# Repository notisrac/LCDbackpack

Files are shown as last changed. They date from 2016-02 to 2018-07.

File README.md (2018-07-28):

# LCD Backpack (serial/I2C)

[Arduino](https://www.arduino.cc/) based character LCD driver circuit, with a form factor that lets it be mounted to the back of a display.
It can be used with any [Hitachi HD44780](https://en.wikipedia.org/wiki/Hitachi_HD44780_LCD_controller) based LCD, or compatible VFD displays (ex.: [Noritake-Itron VFDs](http://www.noritake-itron.com/NewWeb/GVFD/Overview/Overview.asp)).
Supports displays with a single row (1x16) or double row (2x8) connectors.
The display is controlled through a [74HC595](http://www.nxp.com/documents/data_sheet/74HC_HCT595.pdf) shift register.

## Features
* Supports any Hitachi HD44780 based character LCD (or VFD)
* 1x16 and 2x8 pins
* Arduino compatible device with most of the GPIO pins accessible
* Serial and [I2C](https://en.wikipedia.org/wiki/I%C2%B2C) ports
* [FTDI](https://www.adafruit.com/product/284) and (6 pin) [ICSP](https://en.wikipedia.org/wiki/In-system_programming) programming ports
* On-board voltage regulator
* Contrast pot
* Backlight controllable from code (QC pin on the shift register)
* It is the same size as a 16x2 character LCD (also the mounting holes line up)

## Ports
* Serial (D0, D1)
* I2C (A4, A5)
* FTDI header
* ICSP

## Usable Arduino GPIO pins
* Analog: A0, A1, A2, A3, A4, A5
* Digital: D2, D3, D4, D5, D6, D7, D8, D9, D12

## Power supply
The board has an on board power connector, that powers the backpack and the display too.
You can use a voltage regulator like the [LD1117](http://www.st.com/web/en/resource/technical/document/datasheet/CD00000544.pdf), or if you have a regulated power supply, you can just leave it unpopulated and short pins 2 and 3 together.

## Shift register pinout
* QA  - Not connected 
* QB  - LCD RS
* QC  - LCD Backlight control
* QD  - LCD E
* QE  - LCD DB4
* QF  - LCD DB5
* QG  - LCD DB6
* QH  - LCD DB7
* QH* - Not connected
* SER - Arduino D11
* SCK - Arduino D13
* RCK - Arduino D10

## Errata
* Due to the fact, that the enable line of the display is tied to one of the shift register pins, this construction does not work with any of the standard libraries. You need to use the provided library to drive the display!
* In the first version of the board layout the isolation of the ground fill was set to 0. This could have caused a short.

## Pictures
Assembled:
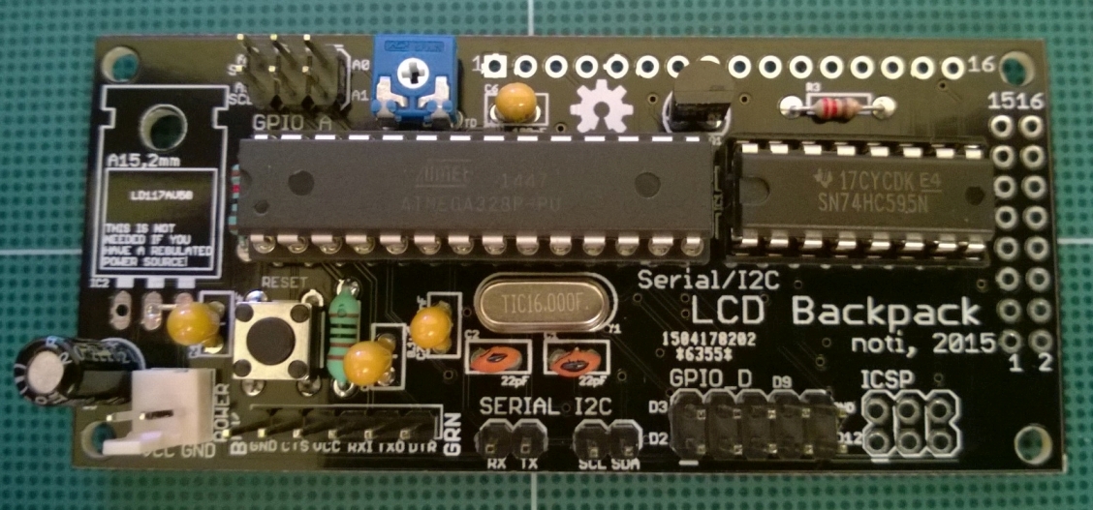
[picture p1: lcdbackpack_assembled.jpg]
LCD backpack assembled


Schematic:
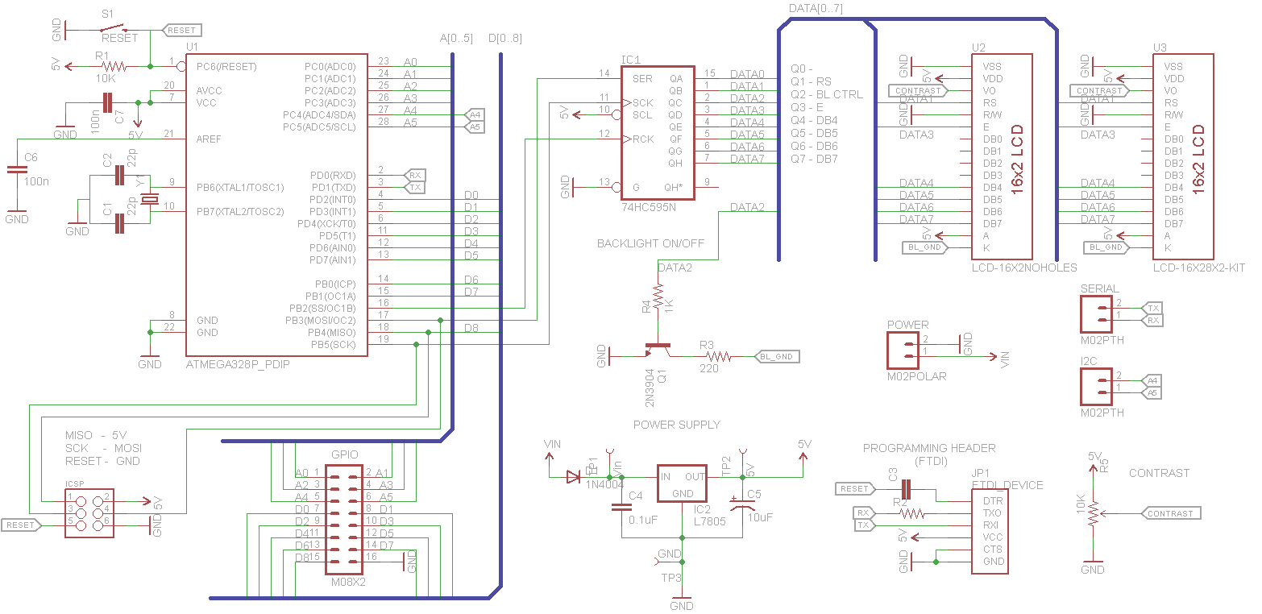
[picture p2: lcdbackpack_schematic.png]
LCD backpack schematic


*Made with Cadsoft Eagle v6.5.0*

Analytics (https://github.com/igrigorik/ga-beacon)

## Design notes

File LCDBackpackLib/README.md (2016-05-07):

# LCDBackpackLib
Since the LCDBackpack uses a different schematic, than the other LCD libraries, you need to use this library to be able to make the LCDBackpack work.

##Acknowledgements
raron's ShiftRegLCD123 - this lib is based on raron's work:
  http://code.google.com/p/shiftreglcd123/

A proper initialization routine for HD44780 compatible LCD's:
  http://web.alfredstate.edu/weimandn/lcd/lcd_initialization/lcd_initialization_index.html

##Schematic
See the project page: https://github.com/notisrac/LCDbackpack

##Connections

  Requires 3 pins from the Arduino.

SR output - Wiring:
*  Bit  #0   - N/C - not connected.
*  Bit  #1   - connects to RS (Register Select) on the LCD
*  Bit  #2   - N/C or LCD backlight. Do not connect directly! Use a driver / transistor!
*  Bit  #3   - connects to LCD Enable input.
*  Bits #4-7 - connects to LCD data inputs D4 - D7.
*  LCD R/!W-pin hardwired to LOW (only writing to LCD).

##Usage

```c
#include <LCDBackpackLib.h>

const byte dataPin = 11;    // SR Data from Arduino pin 10
const byte clockPin = 13;    // SR Clock from Arduino pin 11
const byte latchPin = 10;   // LCD enable from Arduino pin 12

// Instantiate an LCD object
LCDBackpackLib lcdbp(dataPin, clockPin, latchPin);

void setup()
{
	// initialize LCD and set display size
	// LCD size 20 columns x 2 lines, small (normal) font
	lcdbp.begin(20, 2);

	// Turn on backlight (if used)
	lcdbp.backlightOn();

	// Print a message to the LCD.
	lcdbp.print("HELLO, WORLD!");

	// move to next line
	lcdbp.setCursor(0, 1);
	lcdbp.print("LCDBackpackLib test"); 
}

void loop()
{
}
```

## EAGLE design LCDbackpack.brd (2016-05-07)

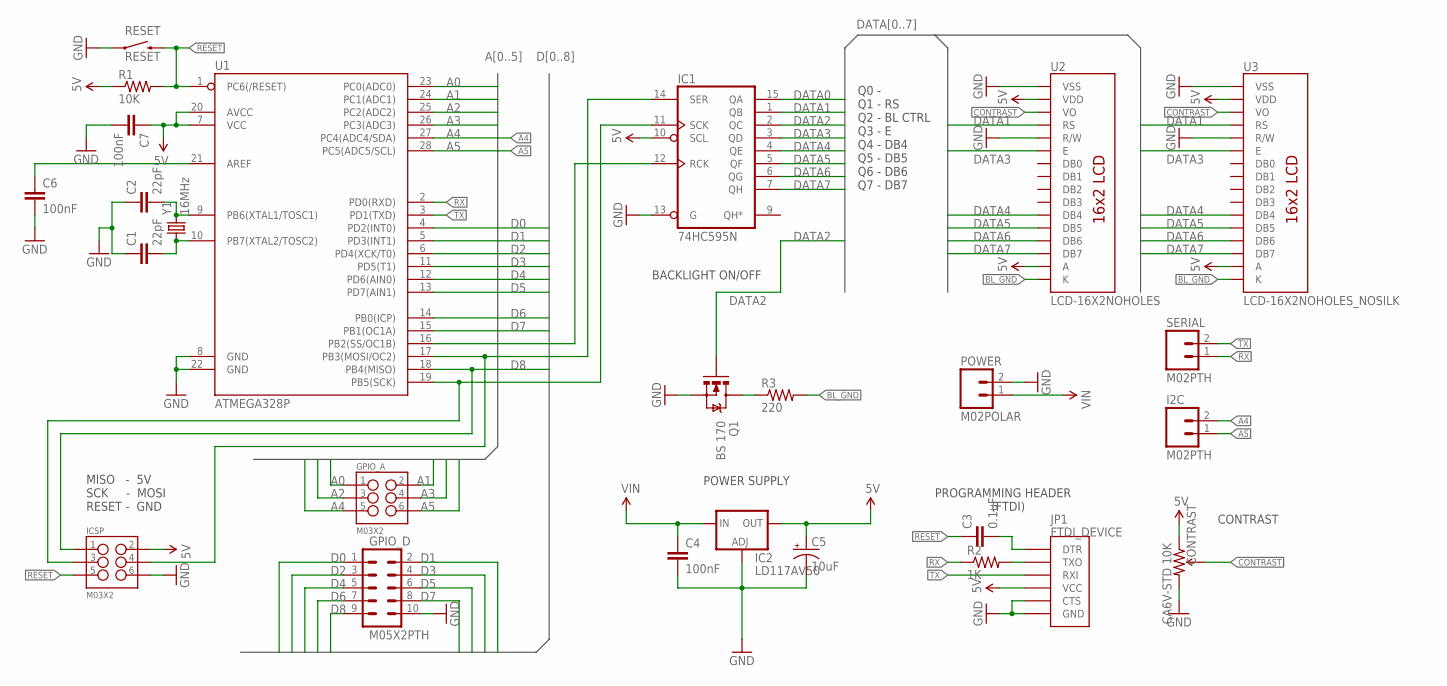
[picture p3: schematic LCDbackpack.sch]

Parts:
C1, C2: 22pF; CAP-PTH-SMALL2
C3: 0.1uF; CAP-PTH-SMALL2
C4, C6, C7: 100nF; CAP-PTH-SMALL2
C5: 10uF; CPOL-RADIAL-10UF-25V
CONTRAST: CA6V-STD 10K; TRIM_POT_PTH
GPIO_A: M03X2; 2X3
GPIO_D: M05X2PTH; AVR_ICSP
I2C: M02PTH; 1X02
IC1: 74HC595N; DIL16
IC2: LD117AV50; TO220L1
ICSP: M03X2; 2X3_POGO
JP1: FTDI_DEVICE; FTDI_DEVICE_SIDE
POWER: M02POLAR; MOLEX-1X2
Q1: BS 170; TO-92
R1: 10K; AXIAL-0.3
R2: 1K; AXIAL-0.3
R3: 220; AXIAL-0.3
RESET: RESET; TACTILE-PTH
SERIAL: M02PTH; 1X02
U1: ATMEGA328P; DIL28-3
U2: LCD-16X2NOHOLES; LCD-16X2_NOHOLES
U3: LCD-16X2NOHOLES_NOSILK; LCD-8X2_NOHOLES_NOSILK
Y1: 16MHz; HC49US

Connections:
A0: GPIO_A.1, U1.23 (PC0(ADC0))
A1: GPIO_A.2, U1.24 (PC1(ADC1))
A2: GPIO_A.3, U1.25 (PC2(ADC2))
A3: GPIO_A.4, U1.26 (PC3(ADC3))
A4: GPIO_A.5, I2C.2, U1.27 (PC4(ADC4/SDA))
A5: GPIO_A.6, I2C.1, U1.28 (PC5(ADC5/SCL))
BL_GND: R3.P$2 (2), U2.16 (K), U3.16 (K)
CONTRAST: CONTRAST.2 (WIPER), U2.3 (VO), U3.3 (VO)
D0: GPIO_D.1, U1.4 (PD2(INT0))
D1: GPIO_D.2, U1.5 (PD3(INT1))
D2: GPIO_D.3, U1.6 (PD4(XCK/T0))
D3: GPIO_D.4, U1.11 (PD5(T1))
D4: GPIO_D.5, U1.12 (PD6(AIN0))
D5: GPIO_D.6, U1.13 (PD7(AIN1))
D6: GPIO_D.7, U1.14 (PB0(ICP))
D7: GPIO_D.8, U1.15 (PB1(OC1A))
D8: GPIO_D.9, ICSP.P$1 (1), U1.18 (PB4(MISO))
DATA0: IC1.15 (QA)
DATA1: IC1.1 (QB), U2.4 (RS), U3.4 (RS)
DATA2: IC1.2 (QC), Q1.2 (G)
DATA3: IC1.3 (QD), U2.6 (E), U3.6 (E)
DATA4: IC1.4 (QE), U2.11 (DB4), U3.11 (DB4)
DATA5: IC1.5 (QF), U2.12 (DB5), U3.12 (DB5)
DATA6: IC1.6 (QG), U2.13 (DB6), U3.13 (DB6)
DATA7: IC1.7 (QH), U2.14 (DB7), U3.14 (DB7)
GND: C1.1, C2.1, C4.2, C5.2 (-), C6.2, C7.2, CONTRAST.3 (CW), GPIO_D.10, IC1.8 (GND), IC1.13 (G), IC2.1 (ADJ), ICSP.P$6 (6), JP1.P$5 (CTS), JP1.P$6 (GND), POWER.2, Q1.1 (S), RESET.1, U1.8 (GND), U1.22 (GND), U2.1 (VSS), U2.5 (R/W), U3.1 (VSS), U3.5 (R/W)
unnamed: C3.2, JP1.P$1 (DTR)
unnamed: JP1.P$2 (TXO), R2.P$2 (2)
unnamed: C2.2, U1.9 (PB6(XTAL1/TOSC1)), Y1.2
unnamed: C1.2, U1.10 (PB7(XTAL2/TOSC2)), Y1.1
unnamed: IC1.14 (SER), ICSP.P$4 (4), U1.17 (PB3(MOSI/OC2))
unnamed: Q1.3 (D), R3.P$1 (1)
unnamed: IC1.12 (RCK), U1.16 (PB2(SS/OC1B))
unnamed: IC1.11 (SCK), ICSP.P$3 (3), U1.19 (PB5(SCK))
unnamed: C6.1, U1.21 (AREF)
RESET: C3.1, ICSP.P$5 (5), R1.P$2 (2), RESET.3 (2), U1.1 (PC6(/RESET))
RX: R2.P$1 (1), SERIAL.1, U1.2 (PD0(RXD))
TX: JP1.P$3 (RXI), SERIAL.2, U1.3 (PD1(TXD))
VCC: C5.1 (+), C7.1, CONTRAST.1 (CCW), IC1.10 (SCL), IC1.16 (VCC), IC2.2 (OUT), ICSP.P$2 (2), JP1.P$4 (VCC), R1.P$1 (1), U1.7 (VCC), U1.20 (AVCC), U2.2 (VDD), U2.15 (A), U3.2 (VDD), U3.15 (A)
VIN: C4.1, IC2.3 (IN), POWER.1

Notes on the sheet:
POWER SUPPLY
PROGRAMMING HEADER (FTDI)
CONTRAST
BACKLIGHT ON/OFF
Q0 - Q1 - RS Q2 - BL CTRL Q3 - E Q4 - DB4 Q5 - DB5 Q6 - DB6 Q7 - DB7
MISO - 5V SCK - MOSI RESET - GND

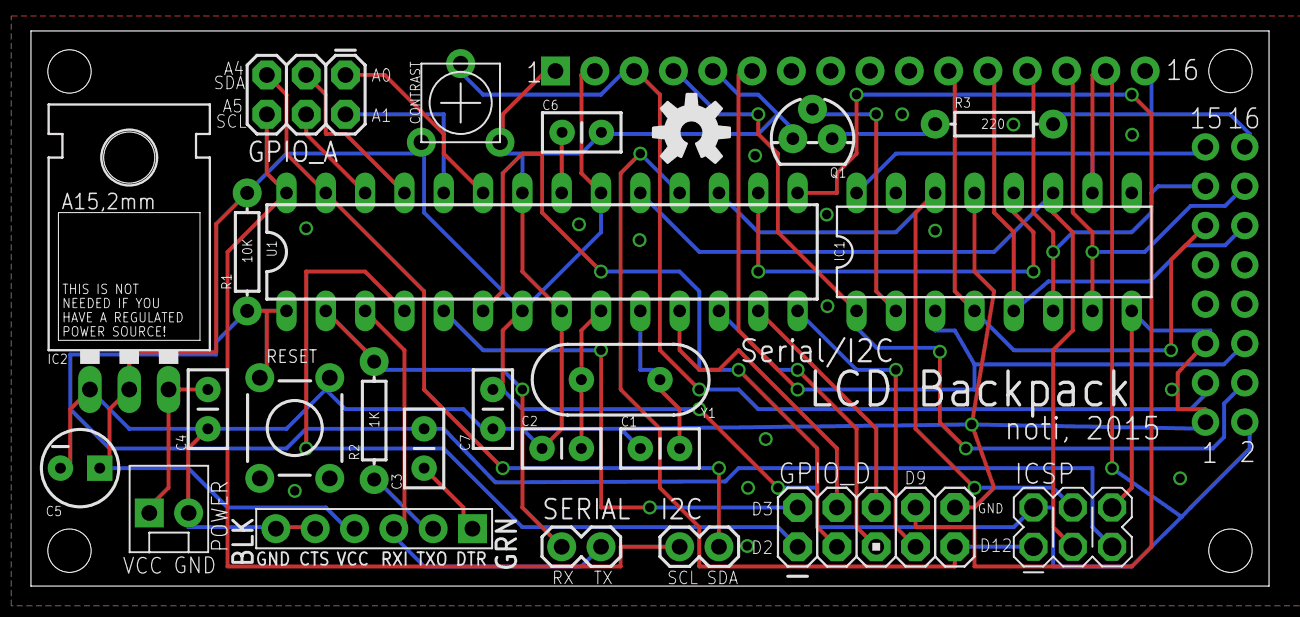
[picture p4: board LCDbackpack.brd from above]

Board: 2 copper layers, 80.0 x 35.9 mm, 27 parts (1 on the bottom side), 39 nets.

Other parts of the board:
U$1: OSHW-LOGO-M

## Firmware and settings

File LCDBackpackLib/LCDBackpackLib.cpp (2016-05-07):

/*

LCDBackpackLib - Arduino library for driving the LCD display on the LCDBackpack


Copyright (C) 2016 noti

GNU GPLv3 license

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

Contact: notix@freemail.hu


Acknowledgements:

  raron's ShiftRegLCD123 - this lib is based on raron's work:
    http://code.google.com/p/shiftreglcd123/
  A proper initialization routine for HD44780 compatible LCD's:
    http://web.alfredstate.edu/weimandn/lcd/lcd_initialization/lcd_initialization_index.html


For reference / schematics:

Project homepage: https://github.com/notisrac/LCDbackpack


CONNECTION DESCRIPTIONS

  Requires 3 pins from the Arduino.

SR output:  Wiring:
  Bit  #0   - N/C - not connected.
  Bit  #1   - connects to RS (Register Select) on the LCD
  Bit  #2   - N/C or LCD backlight. Do not connect directly!
              Use a driver / transistor!
  Bit  #3   - connects to LCD Enable input.
  Bits #4-7 - connects to LCD data inputs D4 - D7.

  LCD R/!W-pin hardwired to LOW (only writing to LCD).


USAGE:

  1: Make an LCD object, set arduino output pins and LCD wiring scheme:

        ShiftRegLCD123 LCDobject( Datapin , Clockpin, Latchpin )

    where:
      Datapin : Arduino pin to shiftregister serial data input. D11
      Clockpin: Arduino pin to shiftregister clock input. D13
      Latchpin: Arduino pin to shiftregister latch/strobe/register clock input. D10

  2: Initialize the LCD by calling begin() function with LCD size and font:

        LCDobject.begin( cols, lines [, font] )

    where:
      cols    : Nr. of columns in the LCD
      lines   : Nr. of "logical lines" in the LCD (not neccesarily physical)
      font    : 0 = small (default), 1 = large font for some 1-line LCD's only.


History
2016.04.17 noti - first version

*/

#include "LCDBackpackLib.h"
#include <stdio.h>
#include <inttypes.h>

#if defined(ARDUINO) && ARDUINO >= 100
#include "Arduino.h"
#else
#include "WProgram.h"
#endif


LCDBackpackLib::LCDBackpackLib(uint8_t srdata, uint8_t srclock, uint8_t srlatch)
{
	init(srdata, srclock, srlatch);
}


void LCDBackpackLib::init(uint8_t srdata, uint8_t srclock, uint8_t srlatch)
{
	_srdata_pin = srdata;
	_srclock_pin = srclock;
	_srlatch_pin = srlatch;
	_backlight = 0;       // Defaults to backlight off.

	pinMode(_srclock_pin, OUTPUT);
	pinMode(_srdata_pin, OUTPUT);
	pinMode(_srlatch_pin, OUTPUT);

	//digitalWrite(_srlatch_pin, LOW);
	shiftOut(_srdata_pin, _srclock_pin, MSBFIRST, 0x00);
	digitalWrite(_srlatch_pin, LOW);
}

void LCDBackpackLib::begin(uint8_t cols, uint8_t lines)
{
	begin(cols, lines, 0);
}

void LCDBackpackLib::begin(uint8_t cols, uint8_t lines, uint8_t font)
{
	_numlines = lines;
	_cols = cols;    // Only used for identifying 16x4 LCD, nothing else.

	if (lines > 1)
	{
		_displayfunction = LCD_4BITMODE | LCD_2LINE;
	}
	else
	{
		_displayfunction = LCD_4BITMODE | LCD_1LINE;
	}


	// For some 1-line displays you can select a 10 pixel high font
	if (font != 0 && lines == 1)
	{
		_displayfunction |= LCD_5x10DOTS;
	}
	else
	{
		_displayfunction |= LCD_5x8DOTS;
	}

	// SEE PAGE 45/46 FOR INITIALIZATION SPECIFICATION!
	// according to datasheet, we need at least 40ms after power rises above 2.7V
	// before sending commands. Arduino can turn on way before 4.5V so we'll wait 
	// more.
	// Also check this -excellent- guide on HD44780-based LCD initializations:
	// http://web.alfredstate.edu/weimandn/lcd/lcd_initialization/lcd_initialization_index.html
	// (From which this initialization and comments are taken from)
	// ---------------------------------------------------------------------------

	// Step 1.   Power on, then delay > 100 ms
	//delay(200);
	for (int i = 0; i < 200; ++i)
	{
		delayMicroseconds(1000);  // Waits 200 ms just in case.
	}

	// Step 2.   Instruction 0011b (3h), then delay > 4.1 ms 
	send(LCD_FUNCTIONSET | LCD_8BITMODE, MODE_INIT);
	delayMicroseconds(4500);  // wait more than 4.1ms

	// Step 3.   Instruction 0011b (3h), then delay > 100 us
	//   NOTE: send()/command() and init4bits() functions adds 60 us delay
	send(LCD_FUNCTIONSET | LCD_8BITMODE, MODE_INIT);
	delayMicroseconds(40);

	// Step 4.   Instruction 0011b (3h), then delay > 100 us 
	send(LCD_FUNCTIONSET | LCD_8BITMODE, MODE_INIT);
	delayMicroseconds(40);

	// Step 5.   Instruction 0010b (2h), then delay > 100 us (speculation)
	//   This is where display is set to 4-bit interface
	send(LCD_FUNCTIONSET | LCD_4BITMODE, MODE_INIT);
	delayMicroseconds(40);

	// Step 6.   Instruction 0010b (2h), then 1000b (8h), then delay > 53 us or check BF 
	//   Set nr. of logical lines (not neccesarily physical lines) and font size
	//   (usually 2 lines and small font)
	command(LCD_FUNCTIONSET | _displayfunction);
	//delayMicroseconds(60);

	// Step 7.   Instruction 0000b (0h), then 1000b (8h) then delay > 53 us or check BF
	command(LCD_DISPLAYCONTROL);
	//delayMicroseconds(60);

	// Step 8.   Instruction 0000b (0h), then 0001b (1h) then delay > 3 ms or check BF 
	//   This is a Clear display instruction and takes a lot of time
	command(LCD_CLEARDISPLAY);
	delayMicroseconds(3000);

	// Step 9.   Instruction 0000b (0h), then 0110b (6h), then delay > 53 us or check BF 
	//   Initialize to default text direction (for romance languages)
	_displaymode = LCD_ENTRYLEFT | LCD_ENTRYSHIFTDECREMENT;
	command(/*LCD_DISPLAYCONTROL*/ LCD_ENTRYMODESET | _displaymode);
	//delayMicroseconds(60);

	// Step 10. Not really a step, but initialization has ended. Except display is turned off.

	// Step 11.   Instruction 0000b (0h), then 1100b (0Ch), then delay > 53 us or check BF
	//   Turn display on, no cursor, no cursor blinking.
	_displaycontrol = LCD_DISPLAYON | LCD_CURSOROFF | LCD_BLINKOFF;
	command(LCD_DISPLAYCONTROL | _displaycontrol);
	//delayMicroseconds(60);
}

// Commands used by the other functions to control the LCD

void LCDBackpackLib::command(uint8_t value)
{
	send(value, MODE_COMMAND);
}

#if defined(ARDUINO) && ARDUINO >= 100
size_t LCDBackpackLib::write(uint8_t value)
#else
void LCDBackpackLib::write(uint8_t value)
#endif
{
	send(value, MODE_WRITE);

	return 1;
}

// For sending data via the shiftregister
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

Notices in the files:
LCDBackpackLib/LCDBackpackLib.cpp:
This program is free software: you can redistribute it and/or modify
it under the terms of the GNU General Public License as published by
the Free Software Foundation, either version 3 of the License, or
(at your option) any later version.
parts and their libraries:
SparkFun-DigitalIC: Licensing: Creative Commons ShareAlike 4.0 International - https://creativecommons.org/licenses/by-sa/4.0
